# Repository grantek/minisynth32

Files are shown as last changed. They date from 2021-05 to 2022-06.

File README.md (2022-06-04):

# Minisynth 32

A 3D-printable MIDI synthesiser inspired by the Roland MT-32 and
[clumsyMIDI](https://github.com/gmcn42/clumsyMIDI), and powered by the
[mt32-pi](https://github.com/dwhinham/mt32-pi/wiki) MT-32 emulator.

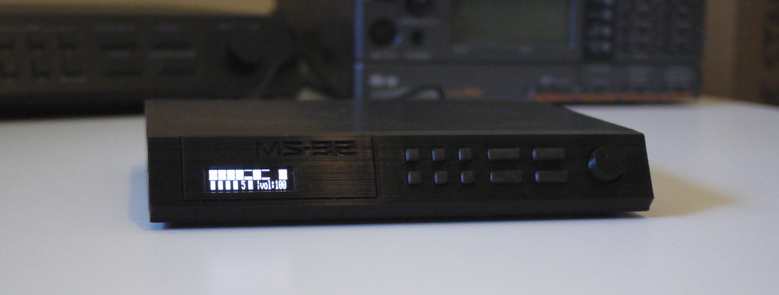
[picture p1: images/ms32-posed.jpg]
Minisynth 32


## Features

* 3D printable shell, 50% scale of the original MT-32
* GY-PCM5102 HiFi DAC board
* Front panel PCB with 2-10 tactile switches and 0.91" OLED Display
* Optional 2- or 10-button clickable front panel (only 2 buttons are functional)
* Rear I/O breakout PCB with 5.5mm power jack and pushbutton power switch
* Rotary encoder volume dial (generic 12mm shaft with no carrier board)
* MIDI Input via DIN5 MIDI cable or USB (using additional Arduino board)
* Completely through-hole soldering, no surface mount components
* Works with the Raspberry Pi "A" or "B" variants

## Warnings

**NO WARRANTY is provided, and no guarantee that all or any of the parts will
fit together. 3D printing is time-consuming and an art at the best of times.**

However, if you're stuck or have a question, feel free to open an issue on
GitHub, and the worst you'll get is sympathy.

## Assembly Notes

Check the [Bill of Materials](minisynth32-bom.csv) for all of the parts needed,
and the [project wiki](https://github.com/grantek/minisynth32/wiki) for the
build guide with pictures, a [text-only copy](build-guide.md) is included in
this repository.

## News

This is "Version 2.0" of the Minisynth 32, the previous version had a simpler
faceplate with 2 large, easy to print buttons. If you're looking for the old
version, see the "ms32-v1.0" tag/release.

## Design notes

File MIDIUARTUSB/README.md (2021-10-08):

# MIDI UART USB converter

This is a cut-down version of https://github.com/gdsports/MIDIUARTUSB for the
Minisynth 32. It only supports MIDI Out from the Tx line of the Arduino to the
Minisynth 32.

Install MIDI Library and MIDIUSB libraries using the Arduino IDE library manager.

Install support for the Sparkfun Pro Micro board in the Arduino IDE by
following the instructions at
https://learn.sparkfun.com/tutorials/pro-micro--fio-v3-hookup-guide/all

## Hardware

MIDIUARTUSB supports several boards based on the ATmega32U4, but the 3D models
for the Minisynth 32 have a spot for a Sparkfun Pro Micro board. I've tested
this with the 5v board only (clone boards are fine).

To interface with the MIDI In lines of the rear I/O PCB:

- Solder a 220 Ohm resistor to the TX0 pad and the VCC pad, each sticking
  straight up.
  - You don't need to leave any spacing between the resistors and the pads, but
    allowing enough to angle them helps with connecting the wires.
  - I haven't tested with a 3.3v Pro Micro board, but if you're using one of
    these, the MIDI specification suggests a 10 Ohm resistor on the TX0 pad,
    and a 33 Ohm resistor on the VCC pad.
- Solder a jumper wire (with a "DuPont" connector on the other end) to each of
  the resistors as per the instructions for connecting the DIN plug.
  - You can optionally add some heatshrink over the resistor-wire connection,
    but I found it wasn't needed.
- Connect the wire attached to the resistor on VCC to "Pin 4" on the rear I/O
  PCB, and the wire attached to the resistor on TX0 to "Pin 5".
- Fix the board to the base of the Minisynth 32 case with some double-sided
  tape.
- You can upload the sketch to the board before or after installing it into the
  Minisynth 32.

Once the sketch is uploaded, the board will show up as a "SparkFun Pro Micro"
when connected to USB, but this should show up as a standard MIDI device as
with any other type of cable.

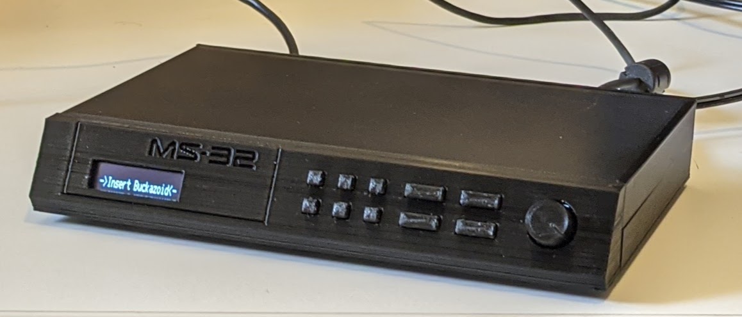
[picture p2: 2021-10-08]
images/ms32.jpg

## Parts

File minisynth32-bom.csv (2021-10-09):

PCBs
PCB Ref | Qnty | Value | Cmp name | Footprint | Description | Vendor
A1, | 1 | GY-PCM5102 | GY-PCM5102 | 1x06_P2.54mm (to attach) | GY-PCM5102 DAC board | Generic
C1, | 1 | 470u 10V | CP1 | Capacitor_THT:CP_Radial_D8.0mm_P3.50mm | Electrolytic capacitor
C2, C4, | 2 | 100n | C | Capacitor_THT:C_Rect_L7.0mm_W2.0mm_P5.00mm | Unpolarized bypass capacitor
C3, | 1 | 100u | CP1 | Capacitor_THT:C_Rect_L7.0mm_W2.0mm_P5.00mm | Electrolytic capacitor
D1, | 1 | 1N4148 | 1N4148 | Diode_THT:D_DO-35_SOD27_P7.62mm_Horizontal | 100V 0.15A standard switching diode, DO-35
J1, | 1 | F_PANEL | Conn_01x06 | 1x06_P2.54mm | Pin header, 6 pins, 90 degree angled
J2, | 1 | Conn_02x20_Odd_Even | Conn_02x20_Odd_Even | 2x20_P2.54mm | Generic connector, double row, 02x20
J3, | 1 | PJ-002A | PJ-002A | Custom THT | 5.5mm barrel power jack, 3-pin footprint | CUI Devices
J4, | 1 | ROT_HDR | Conn_01x04 | 1x04_P2.54mm | Pin header, 4 pins, 90 degree angled
J5, | 1 | MIDI_IN | Conn_01x02 | 1x02_P2.54mm | Pin header, 2 pins, 90 degree angled
J6, | 1 | R_BREAKOUT | Conn_01x06 | 1x06_P2.54mm | Pin header, 6 pins, vertical
J7, | 1 | SSD1306 OLED |  | 1x04_P2.54mm (to attach) | 0.91” OLED display with SSD1306 I2C board | Generic
R1, | 1 | 1k | R | Resistor_THT:R_Axial_DIN0207_L6.3mm_D2.5mm_P7.62mm_Horizontal | Resistor
R2, | 1 | 220R | R | Resistor_THT:R_Axial_DIN0207_L6.3mm_D2.5mm_P7.62mm_Horizontal | Resistor
SW1-SW10 | 10 | TL59NF160Q | TL59NF160Q | Custom THT | 6mm square * 4.3mm tall THT SPST momentary tactile switch | E-Switch
SW11 | 1 | PB400EEQR1BLK | PB400EEQR1BLK or PB400EEQX |  | DPST off-on pushbutton switch. PB400EEQR1BLK comes with a round black cap, PB400EEQX is the same thing without the cap (the round cap can be discarded) | E-Switch
 | 1 |  | TACBLK |  | Rectangular pushbutton cap – black | E-Switch
U1, | 1 | H11L1 | H11L1 | Package_DIP:DIP-6_W7.62mm | Schmitt Trigger Output Optocoupler, High Speed, DIP-6, 1.6mA turn on threshold
Totals:
J1,J4,J5 | 12 | Total angled pins required
J6,A1,J7 | 16 | Total vertical pins required
Other:
 | Qnty | Cmp name | Location | Notes
 | 12 | 2.54mm F-F jumper wires |  | AKA “DuPont” connectors, preferably joined in a ribbon, to be separated into 6-, 4-, and 2-wire ribbons
 | 4 | M2.5*8mm bolt | Raspberry Pi | 8-12mm length should work
 | 4 | M2.5 nut | Raspberry Pi
 | 4 | M3*8mm bolt | Faceplate and DIN socket/MCU clamp | 5-15mm length is fine, M2.5 bolts and nuts will also work here.
 | 4 | M3 nut | Faceplate and DIN socket/MCU clamp
 | 2 | M3*4mm screw | Faceplate and top shell
 | 2 | M3x3mm brass knurled threaded insert | Faceplate and top shell | Usually sold by 3D printing suppliers
 | 1 | 12mm rotary encoder with pushbutton |  | NOT pre-mounted onto a PCB. 12mm shaft height, 6mm shaft diameter
 | 4 | Adhesive rubber feet |  | eg. 3M Bumpon SJ-5508, but anything will work
 | 1 | Raspberry Pi 3 |  | Raspberry Pi 3A or 3B works with rev 1.1+ rear PCB
 | 1 | Micro SD card |  | Any capacity will fit mt32-pi
 | 1 | 5v AC adapter |  | 5.5*2.1mm barrel jack (to fit PJ-002A)
3D printed parts common for all variants:
 | Qnty | Filename | Description | Notes
 | 1 | knob-3.1mm.stl | Volume dial knob | See build guide for fitting notes
 | 1 | top.stl | Top shell
 | 1 | shim-2mm.stl | OLED shim | Helps align the OLED on the front PCB, see build guide for fitting notes
For 10-button face:
 | 1 | face.stl | 10-button face plate | See build guide for printing notes
 | 1 | buttonsheet.stl | 10-button flexible sheet | Print with 0.1mm layer height
For 2-button face:
 | 1 | face-2but.stl | 2-button face plate | Must be printed standing up (not face-down due to hard printed buttons)
 | 1 | buttonsheet-2but.stl | 2-button flexible sheet | Print with 0.1mm layer height
 | 2? | rectbutton.stl | Optional individual rectangular buttons | These have a wider base rather than a flexible sheet, and may be easier (or harder) to print.
 | -8 | TL59NF160Q | Tactile switch | Only 2 switches in total are needed in the B1 and B2 positions of the front PCB
For standard MIDI DIN base:
 | 1 | base-din.stl | Bottom shell | This uses the standard MIDI DIN connector
 | 1 | Panel-mount 180 degree 5-pin DIN connector |  | CUI Devices SD-50SN, but I’ve also seen these sold generically.
For USB base with microcontroller board:
 | 1 | base-mcu.stl | Bottom shell | See MIDIUARTUSB / build guide for notes and Arduino sketch
 | 1 | mcuclamp-sparkfun-pro-micro.stl | Clamp for SF Pro Micro board | See build guide if you need to adjust the height. mcuclamp-arduino-micro.stl suits the Ardiuino Micro.
 | 1 | Sparkfun Pro Micro board | 5v version preferred | Clone boards are usually okay as long as the microcontroller is genuine. Arduino Micro board will also work but extra length interferes with SD Card.
 | 2 | small strips of double-sided adhesive tape |  | To stick the MCU board to the base and add padding pressure. Thickness is around 2mm, otherwise adjust the clamp height.
 | 2 | 220R resistor | Axial lead | For 5v version of Sparkfun Pro Micro board
 | 1? | 10R resistor | Axial lead | Only if using a 3.3v MCU board (untested)
 | 1? | 33R resistor | Axial lead | Only if using a 3.3v MCU board (untested)

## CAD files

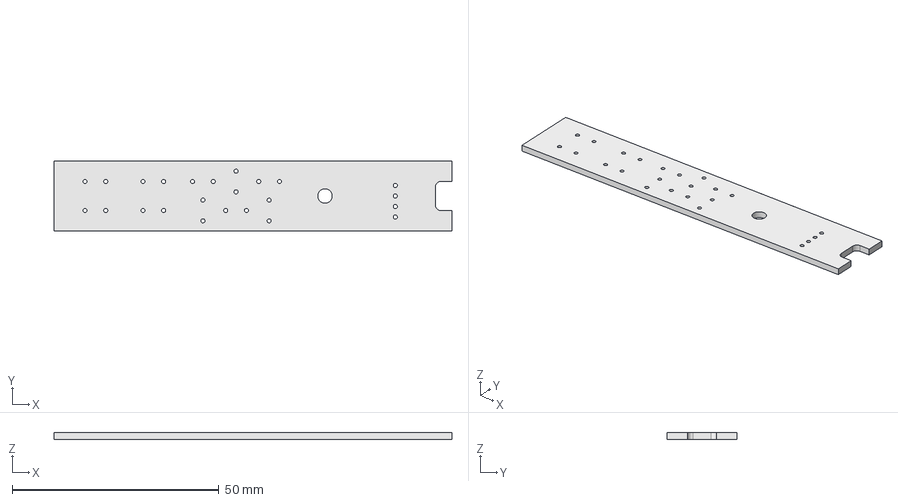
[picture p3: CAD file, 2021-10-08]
3d_models/pcbmock.FCStd
96.2 x 17.0 x 1.60 mm

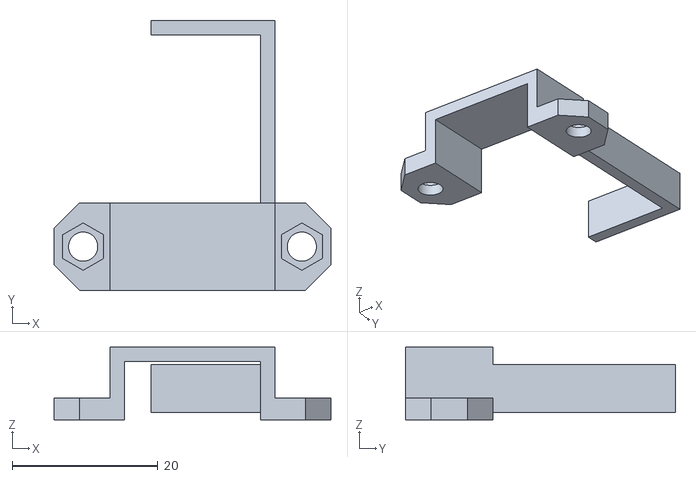
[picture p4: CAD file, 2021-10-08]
3d_models/mcuclamp-arduino-micro.stl
38.0 x 37.0 x 10.0

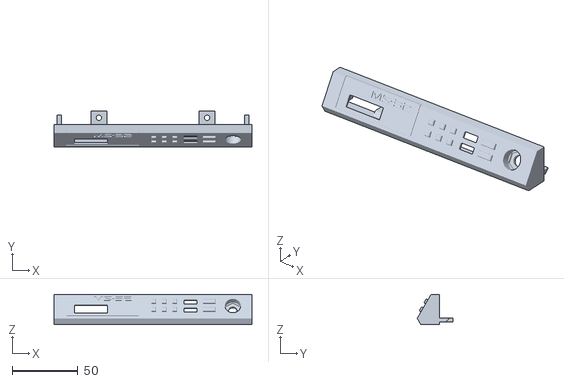
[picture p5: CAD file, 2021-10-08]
3d_models/face-2but.stl
150.0 x 27.0 x 22.9

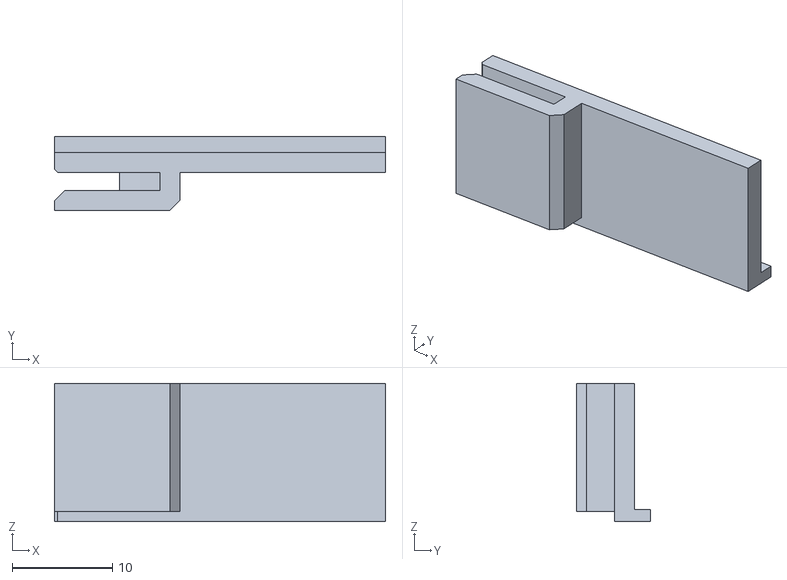
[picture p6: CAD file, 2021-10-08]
3d_models/shim-2mm.stl
33.0 x 7.40 x 13.8

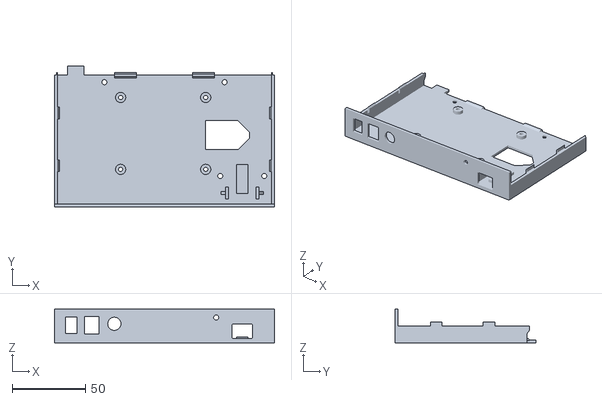
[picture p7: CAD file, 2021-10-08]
3d_models/base-mcu.stl
150.0 x 96.0 x 23.0

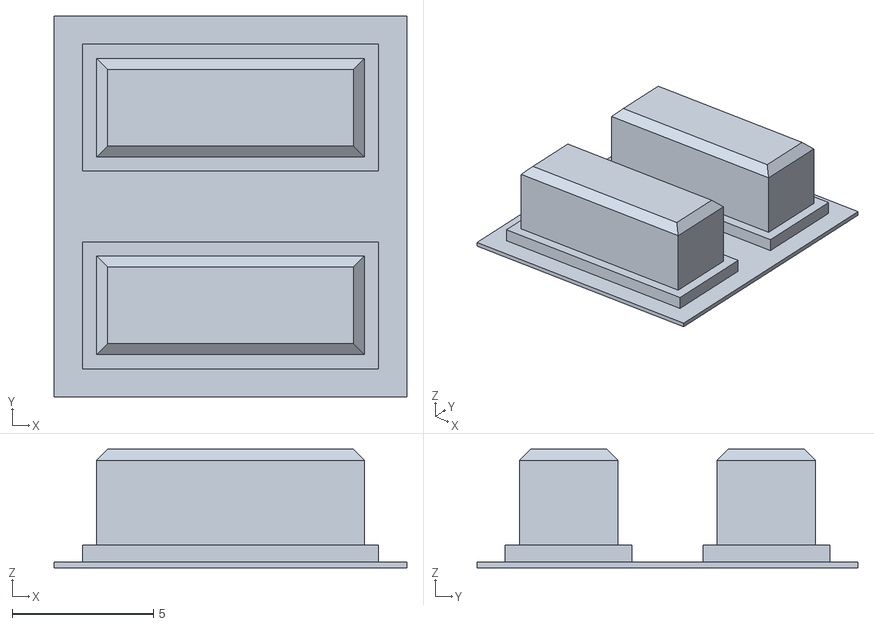
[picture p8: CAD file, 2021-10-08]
3d_models/buttonsheet-2button.stl
12.5 x 13.5 x 4.20

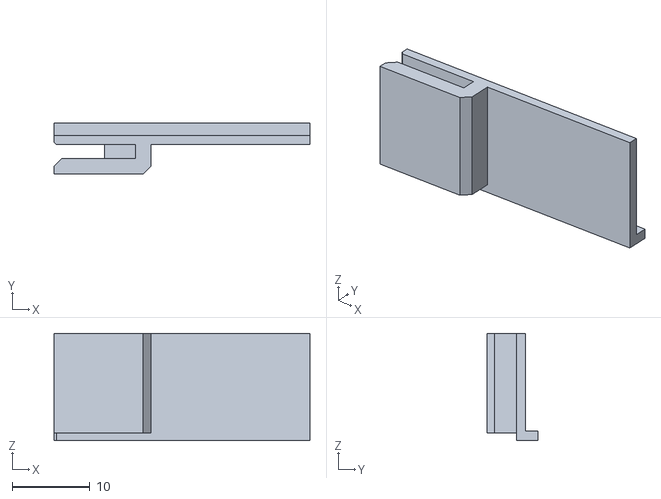
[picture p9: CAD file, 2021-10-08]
3d_models/shim-1.2mm.stl
33.0 x 6.60 x 13.8

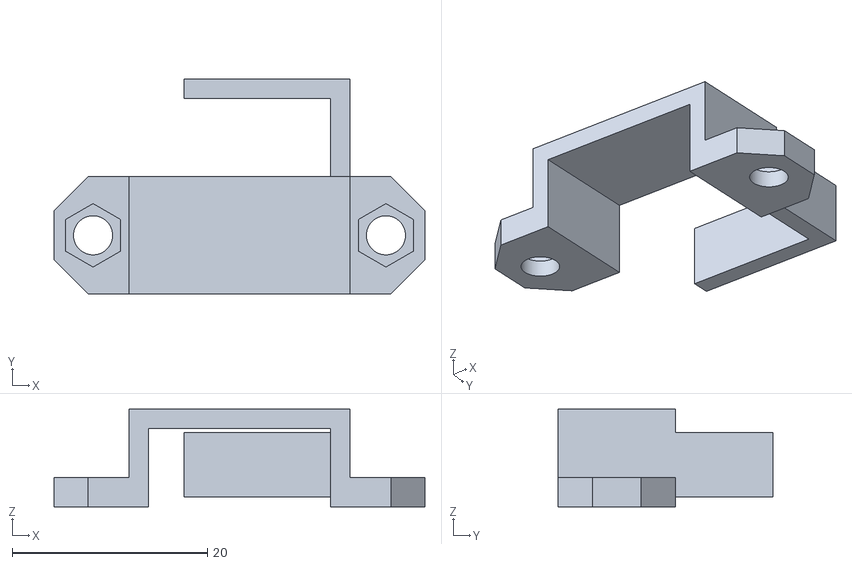
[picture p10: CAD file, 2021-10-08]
3d_models/mcuclamp-sparkfun-pro-micro.stl
38.0 x 22.0 x 10.0

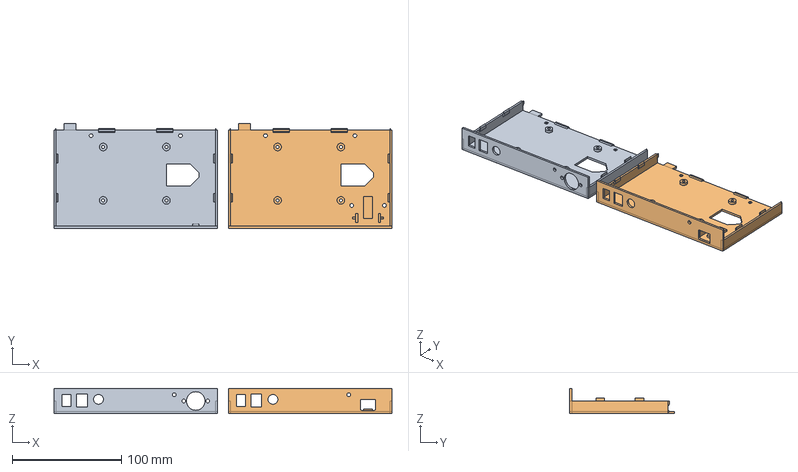
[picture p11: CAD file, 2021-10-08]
3d_models/base.FCStd
310.0 x 96.0 x 23.0 mm
base-din
base-mcu

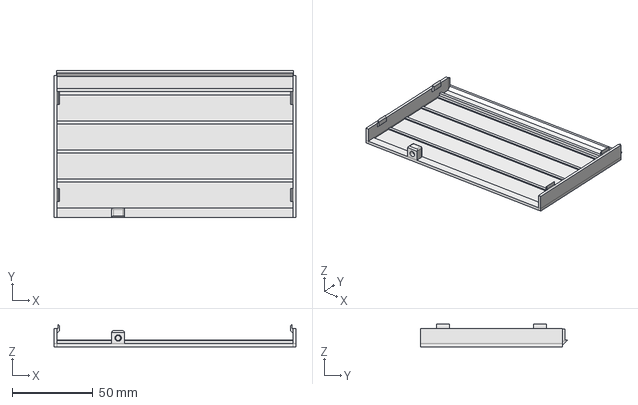
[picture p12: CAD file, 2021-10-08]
3d_models/top.FCStd
150.0 x 91.2 x 14.1 mm

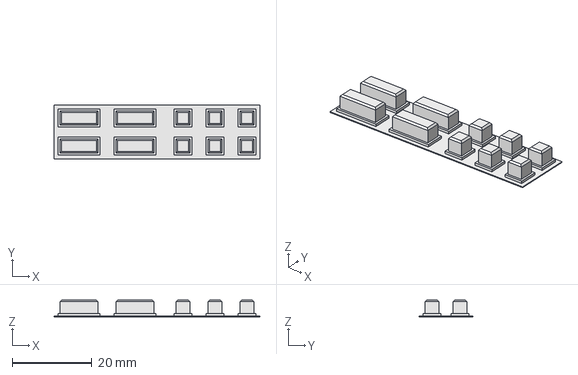
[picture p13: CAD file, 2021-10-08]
3d_models/buttonsheet.FCStd
51.5 x 13.5 x 4.20 mm

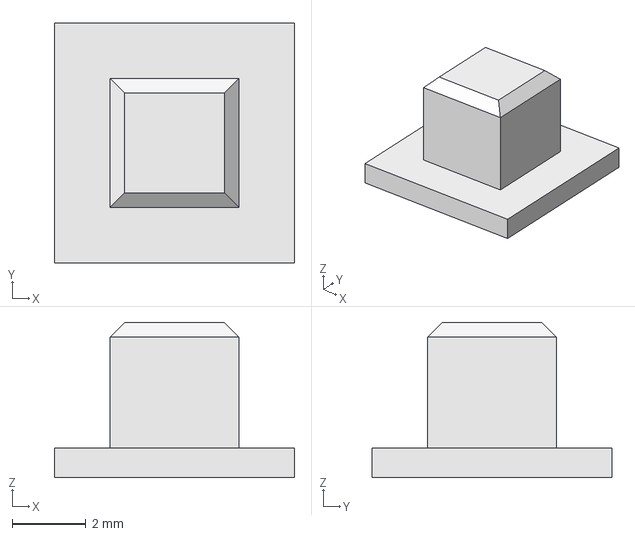
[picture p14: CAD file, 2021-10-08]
3d_models/squarebutton.FCStd
6.50 x 6.50 x 4.20 mm

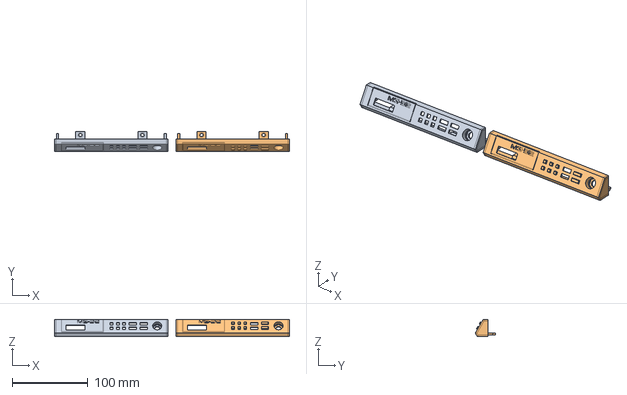
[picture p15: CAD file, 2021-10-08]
3d_models/face.FCStd
310.0 x 27.0 x 22.9 mm
face-2but

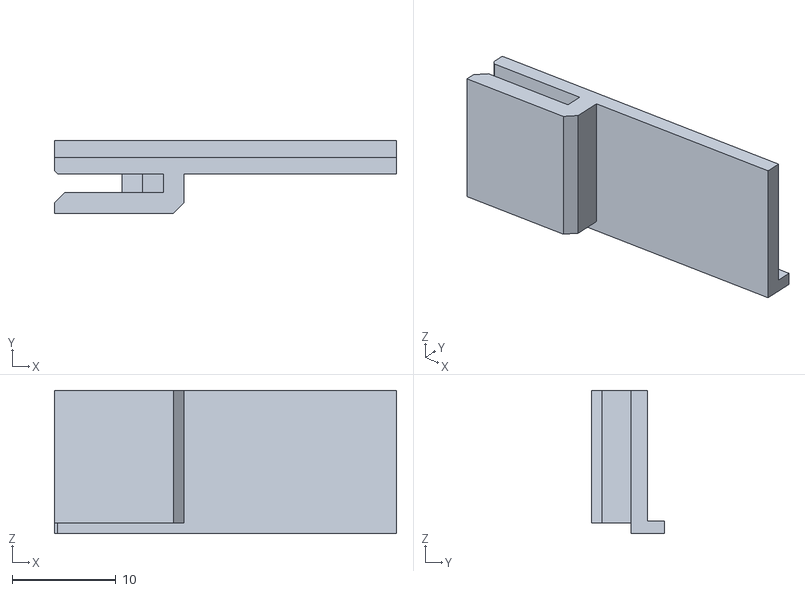
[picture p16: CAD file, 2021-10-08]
3d_models/shim-1.6mm.stl
33.0 x 7.00 x 13.8

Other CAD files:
3d_models/shim-0.8mm.stl
3d_models/rectbutton.FCStd
3d_models/shim.FCStd
3d_models/mcuclamp.FCStd
3d_models/base-din.stl
3d_models/buttonsheet.stl
3d_models/face.stl
3d_models/knob-3.0mm.FCStd
3d_models/knob-3.0mm.stl
3d_models/knob-3.1mm.FCStd
3d_models/knob-3.1mm.stl
3d_models/pcbmock.stl
3d_models/rebackplate.FCStd
3d_models/rectbutton.stl
3d_models/squarebutton.stl
3d_models/top.stl

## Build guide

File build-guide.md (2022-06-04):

# Minisynth 32 Build Guide

Check the [Bill of Materials](minisynth32-bom.csv) for all of the parts needed,
and the [project wiki](https://github.com/grantek/minisynth32/wiki) for the
build guide with pictures.

### MT32-pi configuration

A sample `mt32-pi.cfg` is included in this repository, the options that are
different from the default settings are:

```
# [midi]
# Disable USB input for faster boot time
usb = off

# [audio]
# Output audio to the GY-PCM5102 i2s board
output_device = i2s

# Initialise the GY-PCM5102 DAC on boot
i2c_dac_init = pcm51xx

# [control]
# Use the rotary encoder + 2 buttons control scheme
scheme = simple_encoder

# [lcd]
# Use the ssd1306 driver for the i2c OLED display
type = ssd1306_i2c

# invert the display since it's mounted upside-down in the Minisynth 32
rotation = inverted
```

* The generic 0.91" SSD1306 OLED also works with `height = 64`, and gives
  a sharper but smaller text display. The default `height = 32` is stretched
  but easier to read.
* The generic rotary encoder I used works fine with the `encoder_type = full`
  setting.
* Be sure to check the mt32-pi documentation for setting up the required MT-32
  ROMs and/or GM soundfonts, and other options you may be interested in.

### Choose your variant

#### DIN or USB MIDI input

The rear I/O panel is designed to accept a
[standard MIDI signal](https://www.midi.org/specifications-old/item/midi-din-electrical-specification)
for MIDI input, and the traditional connector for this (as on the Roland MT-32)
is a 180 degree DIN5 socket.

The "base-din.stl" base uses a panel-mount DIN5 socket (mounted on the inside)
connected directly to the input pins on the rear I/O board.

This is the most flexible setup, allowing you to plug in a MIDI cable from a
retro computer or keyboard, or any modern computer with a USB to MIDI cable.

The "base-mcu.stl" base allows you to mount a small Arduino-based
microcontroller board in place of the DIN socket. Using the MIDIUARTUSB sketch
(a cut-down version is included in this repo), the microcontroller acts as a
USB to MIDI cable, with the TX and 5v lines connected to the rear I/O board.

This allows you to connect the Minisynth 32 to a modern computer (or eg. to
a MiSTer) with nothing more than a USB cable

If you can't decide which version to make and don't have a USB to MIDI cable,
consider the DIN version, and make your own external USB to MIDI cable with
an Arduino, some resistors, and a DIN plug. Commercial cables can be found
cheaply, but the cheapest use chips that don't fully implement the MIDI
standard, and won't transmit the SYSEX messages required for MT-32
compatibility reliably.

#### Microcontroller board clamp

If using the USB base, the microcontroller board is clamped down against the
base with a plastic clip. The clip is intended to be used with foam mounting
tape to add some soft pressure to keep the board in place. If you're not using
tape or need to adjust the height of the clamp otherwise, open the
"mcuclamp.FCStd" model in FreeCAD, and adjust the "height of board + padding"
field.

The length of the clamp can also be adjusted to suit different boards.

#### 10-button or 2-button face

The hardware interface to mt32-pi currently only uses 2 buttons for interacting
with the software. The Minisynth 32 has a slightly more authentic 10-button
faceplate, with only 2 of the buttons functional and wired to the Raspberry Pi
(these are the rectangular buttons in the "Sound" and "Sound Group" positions
on the MT-32).

The 10-button version of the faceplate ("face.stl" and "buttonsheet.stl") uses
10 tactile switches to make each button "clickable", even though only 2 are
functional.

The 2-button version of the faceplate ("face-2but.stl" and
"buttonsheet-2button.stl") has clickable buttons in the "Sound" and "Sound
Group" positions, and 8 hard-printed buttons on the face model.

The 10-button version is recommended because it's easier to print (and tiny
clickable buttons are awesome), but the 2-button version is an option if for
some reason you prefer it.

#### Note about OLED board thickness

The 0.91" SSD1306 OLED boards aren't a branded standard, and depending on their
construction they may have different thicknesses. This is due to how the glass
screen is bonded to the PCB. Some use glue or thin tape to stick the glass to
the board, and some use a foam adhesive tape which is a bit thicker.

There is clearance between the Minisynth 32 front panel PCB and the inside of
the face plate to use a slightly thicker OLED board (you don't have to
disassemble and re-glue it), but to allow for different thicknesses (and to
keep the front PCB shorter than 100mm), there is a customiseable 3D-printed
shim that attaches to the front PCB and helps with soldering the OLED board.

The "shim-2mm.stl" is used for an OLED board with the glass directly bonded
to the PCB, and thinner shims can be used if you have an OLED board with some
space between the glass and the PCB.

See the front panel PCB section below for fitting notes. If you need to adjust
the thickness, open shim.FCStd in FreeCAD, open the spreadsheet named "vars",
and edit the value of "shim thickness", then export the shim model as an STL.

### The PCBs

There are 2 PCBs required, the Raspberry Pi hat that the rear connectors are
mounted onto (the "rear I/O breakout board"), and a mounting board for the
front panel. The "front" of the rear board faces downwards, so the components
hang upside down to fit in the tight clearance of the case. The MIDI port is
panel-mounted to the case for the same reason.

The KiCad project is based on a combined board with both PCBs joined by mouse-
bites, so they can be ordered as a single panel. There are also files for the
individual front and rear boards, because it was cheaper for me to order them
this way from the PCB manufacturer I used (there was an extra fee for
"panelised" boards that was more than double the base cost of a single small
board).

PCB notes for manufacturers:

* Rear PCB only (v1.1): 31.7mm * 96mm
* Front PCB only (v2.0): 17mm * 96.2mm
* Panelised front+rear PCB: 51.3mm * 96.2mm
* Minimum hole size: 0.5mm (the standard "0.3mm" is fine to select)
* Minimum track spacing: 0.2mm (the standard "6 mils" is fine to select)
* Layers: 2
* Thickness: must be 1.6mm

### 3D Printing the shell

I'm using a standard hobbyist FFF printer with black PLA filament. The
face plate is kind of terrible for this kind of printing process due to the
different angles involved, but I was successful in printing it upright at a
0.2mm layer height, with the visible layer lines horizontal in the finished
part.

Specifically, use "tree" support for the face if your slicer has the option,
which builds a tower of support starting on the build plate where possible and
reaching across to the overhanging parts.

Regardless of the type of support, there will still be some on the inside of
the faceplate, You need to be thorough in removing it from the inside floor of
the faceplate because the front panel needs to fit in there, but there is some
clearance so one or two layers of support stuck to the floor is okay. Careful
use of a scalpel can help reach behind the PCB support behind the buttons.

The other parts are more straightforward to print, but read through the other
sections for notes on customisation.

The shell was modeled in FreeCAD using the Part workbench, which uses simple
geometric shapes added and subtracted from each other. If you want to modify
the "MS-32" text on the face plate to something more authentic, select the
Model window, press Ctrl-F to search the tree of objects, and search for
ShapeString (the default name for a text object). In the Data window for the
selected object you should be able to change the "MS-32" to something else, and
press Enter. You may also need to supply the font file, I used the "TR-909"
font freely available online.

If the faceplate doesn't update immediately, you should see a check mark on
one or more objects in the tree. Right click on the top-level "face" object
and select "Recompute object".

### Assembling the front panel PCB

See the [Choose your variant](#choose-your-variant) section for options here,
you should have 10 or 2 tactile switches, and a 3D-printed shim to suit your
OLED board.

If you're installing 10 tactile switches, solder these first, as it's easy to
fit them all and then flip the board over with the PCB laying flat on them
before soldering. It doesn't matter if the switches aren't perfectly aligned
in rotation, as long as they're all flat against the PCB.

Take a 4-pin vertical header and solder it to the back of the OLED board, so
that the plastic collar and long ends of the pins face backwards. Solder the
short ends of the pins to the solder points on the front of the board, using
the plastic collar on the back to keep them perpendicular.

If you're using a shim thinner than 1.6mm, you'll need to slide the plastic
collar off the pins so that the OLED board can sit close to the front panel
board (use a blade to start levering the collar backwards).

Clip the shim to the front panel board so that the flat section is on the front
and the tab inside the shim's clip fits into the notch on the front panel
board.

Ideally, do a test fit with the OLED board and shim by installing the board
on top of the shim without soldering the pins onto the front panel PCB, and
try fitting it into the front faceplate. If the PCB doesn't sit flush against
the mounting hole on the faceplate without bending, the shim is too thick.

Once you have a good fit, solder the pins in the front panel board and trim
them.

Solder a 6-pin vertical header to the back of the front panel PCB in the
`R_BREAKOUT` position. The `UNUSED` headers are connected to the non-functional
buttons and don't need pins unless you're experimenting.

### Assembling the rear I/O PCB

The main soldering advice is to solder the DAC board first (see below), then
the generic "lowest-height components first". Make sure to trim all legs on the
underside of the rear breakout PCB, as this faces upwards and there isn't
much room to the printed case.

####  Soldering the DAC module

**IMPORTANT:** As per the clumsyMIDI documentation, make sure that all 4 solder
pad "jumpers" on the GY-PCM5102 board are set BEFORE soldering it to the board.
To solder the GY-PCM5102 DAC board:

- Check the soldered pad headers on the rear of the GY-PCM5102 a final time.
- Solder a 6-pin header to the back of the board (on the short edge), and slide
  the plastic collar off, like the OLED board when using a thin shim.
- Solder the pins through the rear PCB. Alignment of the DAC board is less
  critical here, I used a 2-layer paper shim to help position it while
  soldering it.
- You don't need to solder anything to the row of 9 pins on the long edge,
  there is no connection to anything on the rear breakout board.

####  Soldering the rear panel pin headers

There are 3 pin headers on the rear breakout board that require a 90-degree
angled pin header:

- `F_PANEL`: connects to the front panel PCB, 6 pins.
- `ROT_HDR`: connects to the rotary encoder, 4 pins.
- `MIDI_IN:`: connects to the panel-mount DIN5 jack for MIDI input.

Check the clearance of your pin headers against the Raspberry Pi - if you have
tall pin headers, push them down through the plastic collar so that they just
have room for the jumper wires to connect.

### Assembling the rotary encoder

The rotary encoder used is a "12mm" generic device available online.
Specifically, this is **NOT** a preassembled board with 5-pin header, there's
not enough room for these, so you need to wire directly to the bare legs.

First, bend the mounting tabs on the encoder in against its base.

The pinout from the rear I/O board is labelled `GND` `SW` `B` `A`

* Take a 4-wire jumper cable (ie. with "DuPont" 2.54mm pitch female
  connectors), cut the connectors off one end, strip and tin the cut end of the
  wires.
* When soldering the cut ends to the rotary encoder, you can optionally use
  heatshrink to prevent the exposed legs from touching each other.
* Solder the `GND` wire to the middle pin of the 3-pin side, and from there
  (using another short piece of wire) connect it to one of the
  pins on the 2-pin side.
* Solder the `SW` wire to the other pin on the 2-pin side.
* Solder the `B` wire to the pin on the left of the GND pin.
* Solder the `A` wire to the pin on the right of the GND pin.
* If you get the `B` and `A` pins wrong, you can swap the jumper wires on the
  pin header of the rear breakout board.

The 3D-printed knob for the rotary encoder can be hard to attach firmly. I
found printing the knob in PET-G was best to get a firm fit, but PLA was
less flexible, If the knob won't attach, you can carefully use a clean hot
soldering iron pressed against the rotary encoder's shaft to soften the plastic
in a similar way to the knurled screw inserts. If it's too loose, use some putty
adhesive to hold it in place (this is much easier). There are a few STLs of
different shaft widths, but the FreeCAD model is also easy to modify.

Make sure you have a good fit for the knob before assembling the face plate,
but leave it off when inserting the rotary encoder.

### Assembling the MIDI port for the DIN base

This is similar to the rotary encoder, but it just requires 2 jumper wires
soldered onto the panel-mount DIN5 jack. Looking at the face of the jack with
the pins facing upwards, pin 4 is immediately to the left of the middle pin and
pin 5 is on the right. Heatshrink isn't needed for insulation because the pins
are so far apart, but I used heatshrink to add some mechanical stability to the
connection.

### Setting up the MCU board for the USB base

This repository has 3D models to suit the Sparkfun Pro Micro board (an Arduino-
compatible board), and the Arduino Micro board. The Sparkfun Pro Micro is
recommended because it's shorter and doesn't interfere with the SD card port,
but any of the Arduino boards that use the ATmega32U4 microcontroller will be
compatible if you can fit it in (as mentioned in the intro, you can also leave
the Arduino outside the box as a separate USB-MIDI adapter).

Configuring the Arduino IDE to upload the sketch is outside the scope of this
project, see the links in the [MIDIUARTUSB README](MIDIUARTUSB/README.md).
Things to note:

- Install the MIDI and MIDIUSB libraries in the Arduino IDE
- Install support for the Sparkfun board using the instructions at sparkfun.com

Once you've uploaded the sketch to the board, you need to add resistors and
wires to the board. Solder a 220 ohm resistor onto each of the TX and VCC
points (TX and 5v for the Arduino Micro), and solder DuPont wires in the
way as the DIN port/rotary encoder.

If using a 3.3v microcontroller board, use a 33 ohm resistor on the VCC line and
a 10 ohm resistor on the TX line.

### Assembling the shell

The Raspberry Pi is mounted using M2.5 bolts and nuts. M3 bolts _may_ work
(older versions of the base used M3 screws into threaded inserts), but require
widening the hole slightly, which carries some risk of damaging the Pi.

The faceplate and MIDI port are attached using M3 bolts and nuts. The bolt
lengths don't matter too much, 8-15mm is good. 8mm M2.5 bolts and nuts will also
work here if you're purchasing one type of bolt.

The front PCB, rotary encoder, and top shell are attached using M3\*4mm screws.
M3 PC Case Screws may work here, but if they're any longer than 4mm, it's
possible to push into the plastic resulting in a bulge on the front.

The mounting holes for the front panel PCB, and the top shell use 3mm M3
knurled threaded inserts. These are pushed into the (slightly narrower)
mounting holes of the plastic case with a hot soldering iron to melt them into
the hole (use a similar temperature as your 3D printer extruder, eg. 220-250
Celsius for PLA).

  *  Be careful you don't let the soldering iron touch the other 3D-printed
     parts!
  *  It's easy with a wide conical soldering tip to push the tip of the iron
     into the insert, and hold the insert down with tweezers while you remove
     the iron tip.

### Assembling the face

* Melt the first threaded insert into the faceplate as described above.
* Melt the other threaded insert into the mounting hole on the top shell while
  you're at it.
* The printed face plate is assembled with the assembled front panel PCB, the
  printed button sheet, and the printed knob on the rotary encoder.
* Drop the printed button sheet into the button holes, then fit the front panel
  PCB so that the tactile switches fit against the buttons, and the OLED display
  is aligned with the window. Attach the PCB with an M3 screw.
* Install the rotary encoder:

Remove the hexagonal nut and washer from the encoder, and simply screw the
encoder shaft into the faceplate. There's a cutout in the faceplate to allow
the encoder to spin, but pliers are helpful to rotate it carefully. You may
need to keep screwing it into the plastic once it's in, and slightly strip away
some plastic to get it to line up straight (you'll notice this when installing
the knob).

If the encoder doesn't screw in tightly to the plastic face, put the hexagonal
nut from the rotary encoder into the hexagonal relief in the front of the
faceplate, then screw in the encoder. Even if you prefer to use the hexagonal
nut regardless, screw the encoder into the plastic first to get it straight.

### Assembling the base and top

* Format and prepare your Micro SD card for mt32-pi, and insert it into the
  Raspberry Pi. You can still access the SD card when the Pi is installed, but
  it's easier to do it beforehand.
* Attach the assembled Rear I/O PCB onto the Pi's 40-pin GPIO port, facing
  outwards.
* Line up the Pi on the base with the rear panel, and insert 4 M2.5 bolts
  through the base and mounting holes on the Pi. Secure with 4 M2.5 nuts, but
  do not over-tighten these as excess pressure can damage the Pi.

#### Install the DIN port in the MIDI DIN base

* Place the wired MIDI DIN jack on the **inside** of the base's rear plate, and
  attach with 2 M3 bolts from the outside (M3 nuts on the inside). The DIN5
  jack is traditionally mounted with the pins facing down, and the alignment
  notch facing up. DIN5 cables have an an arrow at the alignment notch for easy
  attachment.
* Connect the DIN jack to the labelled pins on the rear PCB `MIDI_IN` header.
  With the half-circle of DIN pins facing downwards, Pin 4 is left of the
  centre solder tab, and when connected to the rear PCB, the jumper wires
  won't cross.

#### Install the MCU board in the USB base

* Use a piece of padded foam adhesive tape to stick the microcontroller board
  onto the raised section of the base.
* Put a piece of padded foam adhesive tape on top of the ATMega32U4 chip to
  press against the clamp.
* Put the clamp over the MCU board and align the bolt holes.
* Use 3mm bolts and hex nuts to bolt the clamp down and secure the board.
* Connect the VCC/5v wire to Pin 4 on the rear I/O board, and TX to Pin 5.

#### Finishing up

* Connect the wired rotary encoder to the `ROT_HDR` header.
* Use a row of 6 female-female jumper wires to connect the front panel's
  `R_BREAKOUT` header to the rear breakout board's `F_PANEL` header.
* Insert the face plate's tabs into the base, insert a bolt from the bottom of
  the base through each tab in the face plate and fasten with an M3 nut.
* Fit the top shell and fasten with an M3 screw.
* Stick 4 rubber feet (or felt pads, etc.) to the base to give clearance for the
  bolt heads.

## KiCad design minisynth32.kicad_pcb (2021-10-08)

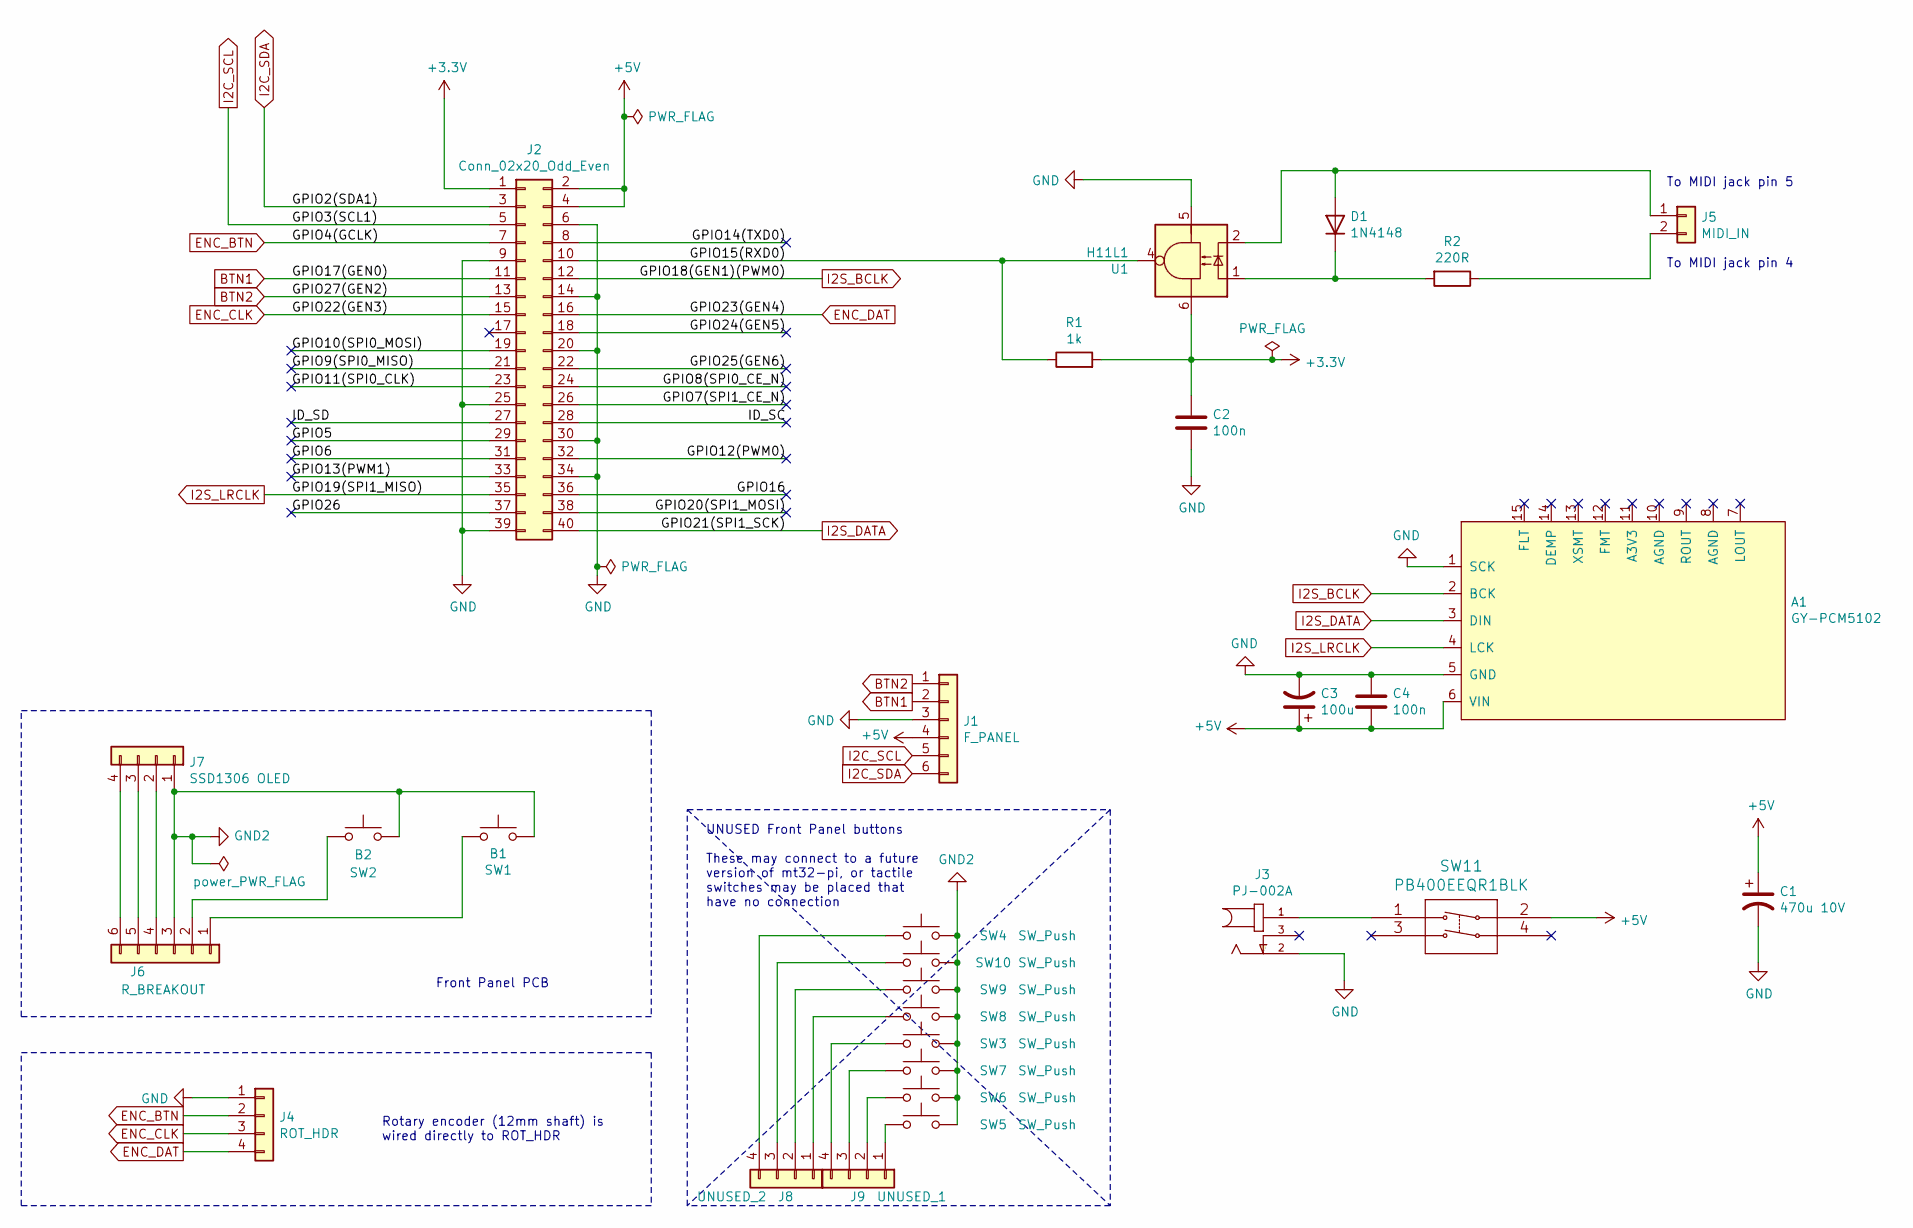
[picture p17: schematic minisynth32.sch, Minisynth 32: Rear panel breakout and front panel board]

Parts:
A1: GY-PCM5102
C1: 470u 10V; CP_Radial_D8.0mm_P3.50mm
C2, C4: 100n; C_Rect_L7.0mm_W2.0mm_P5.00mm
C3: 100u; CP_Radial_D6.3mm_P2.50mm
D1: 1N4148; D_DO-35_SOD27_P7.62mm_Horizontal
J1: F_PANEL; PinHeader_1x06_P2.54mm_Vertical
J2: Conn_02x20_Odd_Even; PinSocket_2x20_P2.54mm_Vertical
J3: PJ-002A; CUI_PJ-002A
J4: ROT_HDR; PinHeader_1x04_P2.54mm_Vertical
J5: MIDI_IN; PinHeader_1x02_P2.54mm_Vertical
J6: R_BREAKOUT; PinHeader_1x06_P2.54mm_Vertical
J7: SSD1306 OLED; SSD1306_128_32
J8: UNUSED_2; PinHeader_1x04_P2.54mm_Vertical
J9: UNUSED_1; PinHeader_1x04_P2.54mm_Vertical
R1: 1k; R_Axial_DIN0207_L6.3mm_D2.5mm_P10.16mm_Horizontal
R2: 220R; R_Axial_DIN0207_L6.3mm_D2.5mm_P10.16mm_Horizontal
SW1: B1; TL59N
SW2: B2; TL59N
SW3, SW4, SW5, SW6, SW7, SW8, SW9, SW10: SW_Push; TL59N
SW11: PB400EEQR1BLK
U1: H11L1; DIP-6_W7.62mm

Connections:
+3V3: C2.1, J2.1, R1.2, U1.6
+5V: A1.6 (VIN), C1.1, C3.1, C4.1, J1.4, J2.2, J2.4, SW11.2
/GPIO5: J2.29
/GPIO6: J2.31
/GPIO7(SPI1_CE_N): J2.26
/GPIO8(SPI0_CE_N): J2.24
/GPIO9(SPI0_MISO): J2.21
/GPIO10(SPI0_MOSI): J2.19
/GPIO11(SPI0_CLK): J2.23
/GPIO12(PWM0): J2.32
/GPIO13(PWM1): J2.33
/GPIO14(TXD0): J2.8
/GPIO15(RXD0): J2.10, R1.1, U1.4
/GPIO16: J2.36
/GPIO20(SPI1_MOSI): J2.38
/GPIO24(GEN5): J2.18
/GPIO25(GEN6): J2.22
/GPIO26: J2.37
/ID_SC: J2.28
/ID_SD: J2.27
BTN1: J1.2, J2.11
BTN2: J1.1, J2.13
ENC_BTN: J2.7, J4.2
ENC_CLK: J2.15, J4.3
ENC_DAT: J2.16, J4.4
GND: A1.1 (SCK), A1.5 (GND), C1.2, C2.2, C3.2, C4.2, J1.3, J2.6, J2.9, J2.14, J2.20, J2.25, J2.30, J2.34, J2.39, J3.2, J4.1, U1.5
GND2: J6.3, J7.1, SW1.2, SW2.2, SW3.2, SW4.2, SW5.2, SW6.2, SW7.2, SW8.2, SW9.2, SW10.2
I2C_SCL: J1.5, J2.5
I2C_SDA: J1.6, J2.3
I2S_BCLK: A1.2 (BCK), J2.12
I2S_DATA: A1.3 (DIN), J2.40
I2S_LRCLK: A1.4 (LCK), J2.35
unnamed: D1.1 (K), R2.2, U1.1
unnamed: D1.2 (A), J5.1, U1.2
unnamed: J3.1, SW11.1
unnamed: J5.2, R2.1
unnamed: J6.1, SW1.1
unnamed: J6.2, SW2.1
unnamed: J6.4, J7.2
unnamed: J6.5, J7.3
unnamed: J6.6, J7.4
unnamed: J8.1, SW8.1
unnamed: J8.2, SW9.1
unnamed: J8.3, SW10.1
unnamed: J8.4, SW4.1
unnamed: J9.1, SW5.1
unnamed: J9.2, SW6.1
unnamed: J9.3, SW7.1
unnamed: J9.4, SW3.1

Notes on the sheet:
To MIDI jack pin 4
To MIDI jack pin 5
Rotary encoder (12mm shaft) is wired directly to ROT_HDR
Front Panel PCB
UNUSED Front Panel buttons These may connect to a future version of mt32-pi, or tactile switches may be placed that have no connection

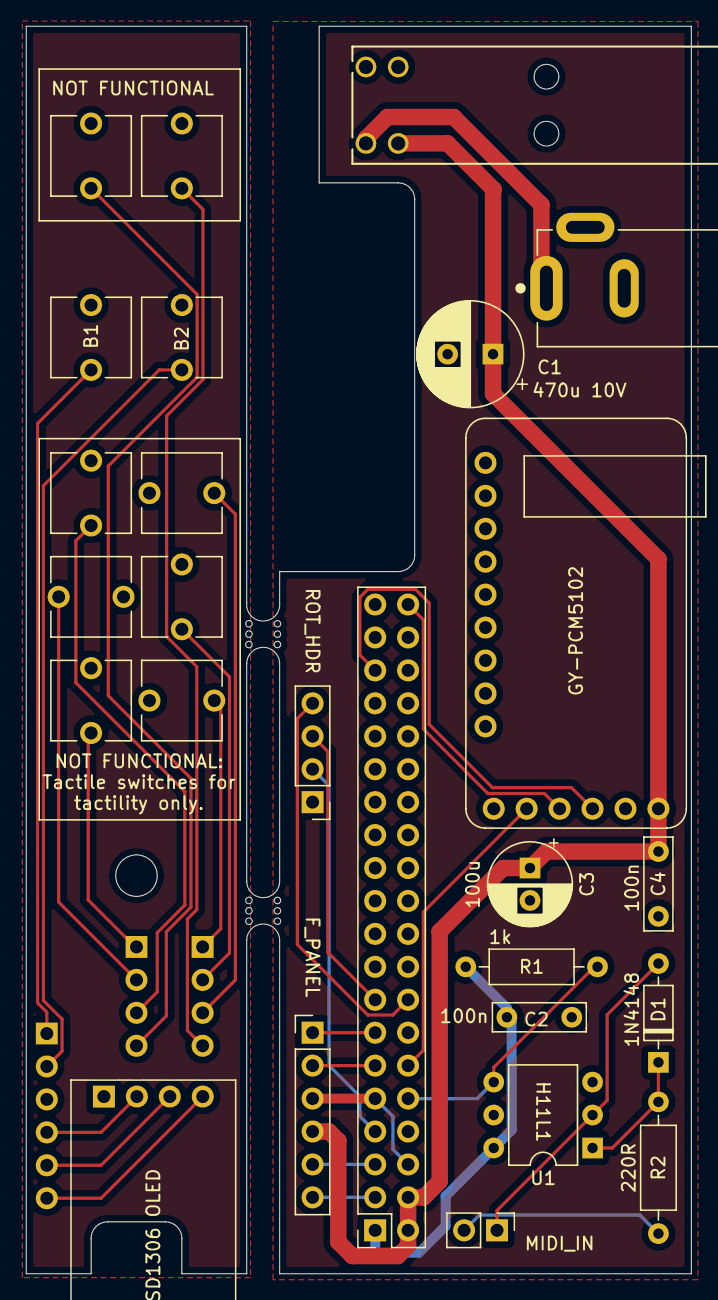
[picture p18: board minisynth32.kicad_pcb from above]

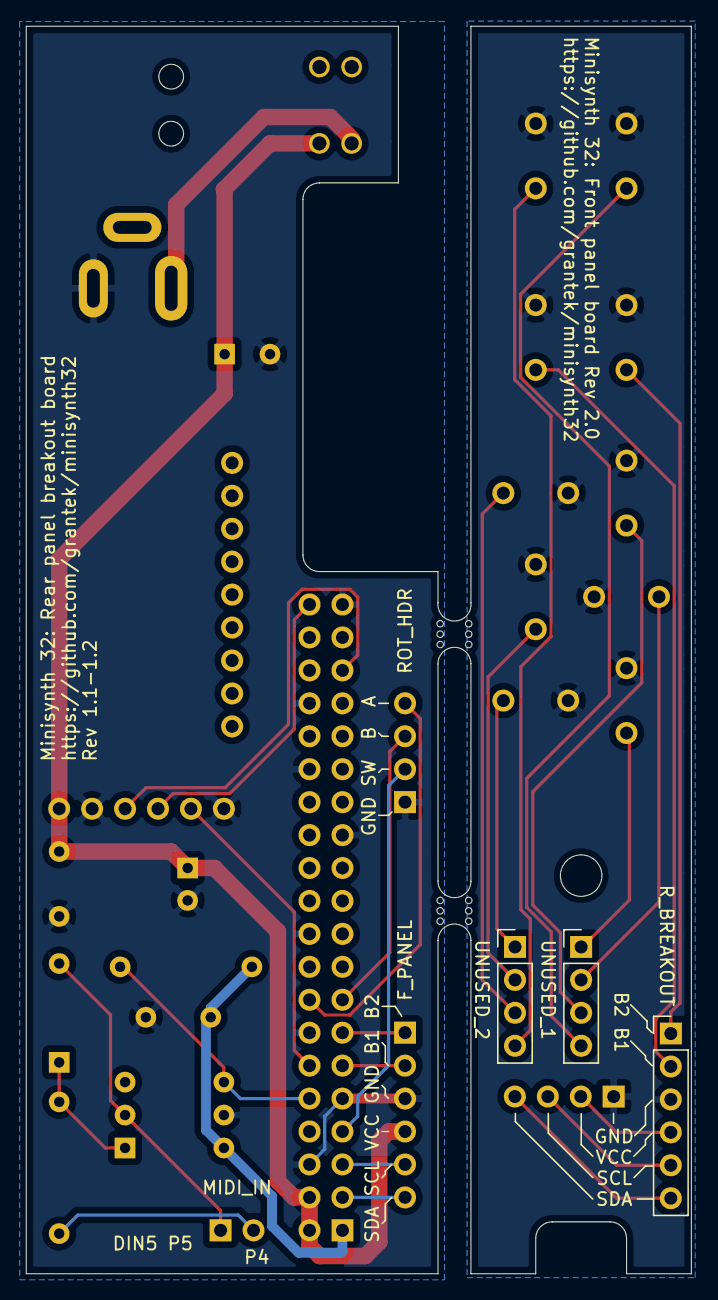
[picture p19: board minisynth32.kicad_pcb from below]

Board: 2 copper layers, 51.3 x 96.2 mm, 31 parts (3 on the bottom side), 32 nets.

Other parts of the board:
mouse-bite-2.54mm-slot, mouse-bite-2.54mm-slot#2: VAL**; mouse-bite-2.54mm-slot

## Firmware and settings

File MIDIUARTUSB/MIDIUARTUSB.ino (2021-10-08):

/*
  MIT License

  Copyright (c) 2018 gdsports625@gmail.com

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
  THE SOFTWARE IS PROVIDED "AS IS", WITHOUT WARRANTY OF ANY KIND, EXPRESS OR
  IMPLIED, INCLUDING BUT NOT LIMITED TO THE WARRANTIES OF MERCHANTABILITY,
  FITNESS FOR A PARTICULAR PURPOSE AND NONINFRINGEMENT. IN NO EVENT SHALL THE
  AUTHORS OR COPYRIGHT HOLDERS BE LIABLE FOR ANY CLAIM, DAMAGES OR OTHER
  LIABILITY, WHETHER IN AN ACTION OF CONTRACT, TORT OR OTHERWISE, ARISING FROM,
  OUT OF OR IN CONNECTION WITH THE SOFTWARE OR THE USE OR OTHER DEALINGS IN THE
  SOFTWARE.
*/

/*
   MIDIUARTUSB converter for 32u4 such as Leonardo, Pro Micro, Itsy Bitsy.

   Original sketch: https://github.com/gdsports/MIDIUARTUSB

   Modified for Minisynth32 to only include "MIDI out" functionality to the
   synth unit.

   Intended for Ardiono Pro Micro, but see the main project for notes on other
   boards this may work with.
*/

#include <MIDI.h>
#include <MIDIUSB.h>

// 1 turns on debug, 0 off
#define DBGSERIAL if (0) SERIAL_PORT_MONITOR
#ifdef USBCON
#define MIDI_SERIAL_PORT Serial1
#else
#define MIDI_SERIAL_PORT Serial
#endif

struct MySettings : public midi::DefaultSettings
{
  static const bool Use1ByteParsing = false;
  static const unsigned SysExMaxSize = 1026; // Accept SysEx messages up to 1024 bytes long.
  static const long BaudRate = 31250;
};

MIDI_CREATE_CUSTOM_INSTANCE(HardwareSerial, MIDI_SERIAL_PORT, MIDIUART, MySettings);

inline uint8_t writeUARTwait(uint8_t *p, uint16_t size)
{
  // Apparently, not needed. write blocks, if needed
  //  while (MIDI_SERIAL_PORT.availableForWrite() < size) {
  //    delay(1);
  //  }
  return MIDI_SERIAL_PORT.write(p, size);
}

uint16_t sysexSize = 0;

void sysex_end(uint8_t i)
{
  sysexSize += i;
  sysexSize = 0;
}

const uint8_t MIDI_passthru_pin=2;
bool MIDI_passthru;

void setup() {
  // Turn off built-in RED LED
  pinMode(LED_BUILTIN, OUTPUT);
  digitalWrite(LED_BUILTIN, LOW);

  DBGSERIAL.begin(115200);

  // Pin 0 LOW selects MIDI pass through on
  pinMode(MIDI_passthru_pin, INPUT_PULLUP);
  MIDI_passthru = (digitalRead(MIDI_passthru_pin) == LOW);

  MIDIUART.begin(MIDI_CHANNEL_OMNI);
  if (MIDI_passthru) {
    DBGSERIAL.println("MIDI thru on");
  }
  else {
    DBGSERIAL.println("MIDI thru off");
    MIDIUART.turnThruOff();
  }
}

void loop()
{
  /* MIDI USB -> MIDI UART */
  midiEventPacket_t rx = MidiUSB.read();
  if (rx.header != 0) {
    switch (rx.header & 0x0F) {
      case 0x00:  // Misc. Reserved for future extensions.
        break;
      case 0x01:  // Cable events. Reserved for future expansion.
        break;
      case 0x02:  // Two-byte System Common messages
      case 0x0C:  // Program Change
      case 0x0D:  // Channel Pressure
        writeUARTwait(&rx.byte1, 2);
        break;
      case 0x03:  // Three-byte System Common messages
      case 0x08:  // Note-off
      case 0x09:  // Note-on
      case 0x0A:  // Poly-KeyPress
      case 0x0B:  // Control Change
      case 0x0E:  // PitchBend Change
        writeUARTwait(&rx.byte1, 3);
        break;
      case 0x04:  // SysEx starts or continues
        sysexSize += 3;
        writeUARTwait(&rx.byte1, 3);
        break;
      case 0x05:  // Single-byte System Common Message or SysEx ends with the following single byte
        sysex_end(1);
        writeUARTwait(&rx.byte1, 1);
        break;
      case 0x06:  // SysEx ends with the following two bytes
        sysex_end(2);
        writeUARTwait(&rx.byte1, 2);
        break;
      case 0x07:  // SysEx ends with the following three bytes
        sysex_end(3);
        writeUARTwait(&rx.byte1, 3);
        break;
      case 0x0F:  // Single Byte, TuneRequest, Clock, Start, Continue, Stop, etc.
        writeUARTwait(&rx.byte1, 1);
        break;
    }
  }
}

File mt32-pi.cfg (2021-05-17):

#                                  ________    _______                      __
#                         __      /_____   `. /____   `.                   /__`
#     ____   ____     __/  /____  _______)  / ______)  / ____  ______      __
#   /   __ v  __  `./__   _____//_____    < /   _____. /____//   ___  `. /  /
#  /  /  /  /  /  /   /  /____  _______)  //  /______       /  /____/  //  .__
# /__/  /__/  /__/    \______//_________. /_________/      /   ______.  \____/
# /////////////////////////////////////////////////////// /  / //// /// // /
#                                                         ```
# mt32-pi.cfg: mt32-pi configuration file.
# Default options are marked with an asterisk (*).

# -----------------------------------------------------------------------------
# System options
# -----------------------------------------------------------------------------
[system]

# Set the default synthesizer to be made active on startup.
#
# If the default synthesizer is unavailable (e.g. missing ROMs or SoundFonts),
# the first working synth is made active.
#
# Values: mt32*, soundfont
#
# mt32:      Use mt32emu (Munt) for Roland MT-32 emulation
# soundfont: Use FluidSynth for SoundFont synthesis
default_synth = mt32

# Enable or disable support for USB devices.
#
# Disable this to speed up boot time if you are not using any USB devices.
#
# Values: on*, off
usb = off

# Set the I2C baud rate/clock speed for all peripherals (Hz).
#
# Most peripherals will work fine at the default speed (400KHz "fast mode"),
# but larger LCD/OLED displays (e.g. 4-line I2C HD44780 and 64 pixel high
# SSD1306) won't be able to refresh at 60FPS at the default setting.
#
# Try increasing this value to 1000000 (1MHz) for a smoother LCD refresh rate.
# If your display doesn't work, try backing off the speed 100KHz at a time
# until it does.
#
# Values: 100000-1000000 (400000*)
i2c_baud_rate = 400000

# Set the timeout for power saving mode (seconds).
#
# After the specified number of seconds of silence, the CPU clock speed will be
# reduced, the audio device will be stopped, and and the LCD's backlight will
# be turned off to save energy (certain I2C displays only).
#
# Any MIDI activity will instantly bring the system out of power saving mode.
#
# If set to 0, power saving mode is disabled.
#
# Values: 0-3600 (300*)
power_save_timeout = 300

# -----------------------------------------------------------------------------
# MIDI options
# -----------------------------------------------------------------------------
[midi]

# Set the baud rate used for GPIO MIDI.
#
# For connecting to standard MIDI devices (i.e. via DIN cable), this should be
# left at the default rate of 31250.
#
# For connecting to PCs, set this to match the baud rate of the other host.
# SoftMPU's serial MIDI mode, for example, uses a baud rate of 38400.
#
# Values: 300-4000000 (31250*)
gpio_baud_rate = 31250

# Enable or disable software "MIDI thru" on the GPIO Tx pin.
#
# When enabled, all data received via the GPIO Rx pin will be re-transmitted
# verbatim on the Tx pin. This may be useful for debugging or for passing MIDI
# data through to another synth.
#
# Values: on, off*
gpio_thru = off

# -----------------------------------------------------------------------------
# Audio options
# -----------------------------------------------------------------------------
[audio]

# Select audio output device.
#
# Values: pwm*, i2s
#
# pwm: Use the headphone jack
# i2s: Use an I2S DAC
output_device = i2s

# Sample rate of audio output (Hz).
#
# mt32emu uses an internal sample rate of 32000Hz (just like the real hardware)
# which is then resampled to this value.
#
# FluidSynth renders at this sample rate directly.
#
# Values: 32000-192000 (48000*)
sample_rate = 48000

# Set audio rendering chunk size (samples).
#
# A single stereo frame of audio has two samples, and so this value is double
# the number of frames per chunk.
# The smaller the chunk size, the lower the latency, but too low a value will
# cause underruns (distortion artifacts).
#
# Latency is a function of chunk size and sample rate, for example:
# 256 samples / 2 channels / 48000Hz * 1000ms = 2.67ms of latency.
# See documentation for recommended values for various Raspberry Pi models.
#
# The minimum value varies depending on audio output device.
# For PWM, the minimum is 2, for I2S the minimum is 32.
#
# Values: 2-2048 (256*)
chunk_size = 256

# Set address (hexadecimal) of I2C DAC control interface.
#
# This will be used for the initialization sequence (see below) if enabled.
# You can find the address of your DAC by using the i2cdetect utility in Linux.
#
# Values: 00-80 (4c*)
i2c_dac_address = 4c

# Select an initialization sequence for the DAC.
#
# Some DACs require some initialization commands to be sent via I2C before they
# will produce any sound.
#
# Values: none*, pcm51xx
#
# pcm51xx: for DACs based on PCM5121 or similar (e.g. PCM5141, PCM5242)
i2c_dac_init = pcm51xx
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

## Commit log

2021-05-07 Initial commit: Rear/Front PCB v1.0
    [minisynth32.kicad_pcb, minisynth32.sch]
2021-05-08 Move ROT_HDR for RPi 3B
    [minisynth32.kicad_pcb]
2021-05-10 Add separate PCB files, gerbers, readme, license, bom
    [minisynth32-B_Cu.gbl, minisynth32-B_Mask.gbs, minisynth32-B_SilkS.gbo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]
2021-05-11 Add 3D models
    [backplate.FCStd, backplate.stl, base.FCStd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]
2021-05-11 Update shell, README
    face:
    - add clearance to edges and bolt mounts
    - add hex nut pockets to bolt mounts
    - add face lines to imitate MT-32 display plate
    face, base, top:
    - new mating lips with more clearance
    base, top:
    - new mating lips similar to face
    - Minor updates to README
    - Delete old backplate model
    Also add .FCStd1 (FreeCAD backup files) to .gitignore
    [backplate.FCStd, backplate.stl, base.FCStd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]
2021-05-13 PCB rev 1.1 (rear only): cutaway to support RPi3B
    [minisynth32-B_Cu.gbl, minisynth32-B_Mask.gbs, minisynth32-B_SilkS.gbo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]
2021-05-15 Rev 1.1 F/R PCBs, tuned base and top
    [base.FCStd, base.stl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]
2021-05-17 Minor 3D updates and documentation
    [base.FCStd, base.stl, knob-3.0mm.FCStd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]
2021-05-18 Minor updates to face
    - standardise cuts for the threaded inserts
    - add hard support for knobwall
    [face.FCStd, face.stl]
2021-05-30 Change Pi mounting to M2.5 bolts
    Updated BOM/README/CHANGELOG to suit.
    Also properly rotated face "knobwall" hard support so it doesn't interfere with the backplate.
    [base.FCStd, base.stl, face.FCStd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]
2021-07-08 Documentation updates
    [minisynth32-bom.csv]
2021-08-01 WIP face v2
    [face.FCStd]
2021-08-01 Add rebackplate.FCstd (only had STL there)
    [rebackplate.FCStd]
2021-08-17 face v2
    [base.FCStd, base.stl, button.FCStd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]
2021-08-25 front pcb v2
    [face.FCStd, face.stl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]
2021-08-26 doco and stuff
    [minisynth32-bom.csv, shim-1.2mm.stl, shim-2mm.stl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]
2021-09-01 10-button updates
    [buttonmatrix.FCStd, buttonmatrix.stl, buttonmatrix2.FCStd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]
2021-09-06 arduino pro micro variant of base
    [base-apm.stl, base-din.stl, base.FCStd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]
2021-09-07 add MIDIUARTUSB, clean up models, update BOM
    [buttonmatrix.FCStd, buttonmatrix.stl, buttonsheet-2button.stl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]
2021-09-28 remove oled clearance as it was causing artifacts in the front face
    [face.FCStd, face.stl]
2021-10-02 updates to 3d models
    - redo bottom lip to suit base tabs
    - rework clearance cuts
    base:
    - tune reclearancefill
    - work on usb apm mount
    apmclamp:
    - bolt-from-bottom clamp to secure arduino pro micro from top
    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
    [apmclamp.FCStd, apmclamp.stl, base-apm.stl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]
2021-10-06 Update models
    - fix base wall mirroring (was incorrectly rotated before)
    - rework MCU base to fit different types of MCU board
    - add parametric (via spreadsheet) MCU clamp
    - remove 2mm shim STL as testing showed it too thick for thin OLED board
    [apmclamp.FCStd, apmclamp.stl, base-apm.stl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]
2021-10-06 render face-2but and create separate tree in FCStd
    [face-2but.stl, face.FCStd]
2021-10-07 Silkscreen update to front and F/R PCBs
    Updated Silkscreen text for extra buttons to read "NOT FUNCTIONAL" instead of "UNUSED", and got rid of the cross through them to avoid confusion.
    [minisynth32-B_Cu.gbl, minisynth32-B_Mask.gbs, minisynth32-B_SilkS.gbo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]
2021-10-07 Update BOM and README
    Also re-add 2mm shim
    [minisynth32-bom.csv, shim-2mm.stl, shim.FCStd]
2021-10-07 Lower MCU default boardheight to 5mm
    [mcuclamp-arduino-micro.stl, mcuclamp-sparkfun-pro-micro.stl, mcuclamp.FCStd]
2021-10-08 lengthen lip on top shell
    [top.FCStd, top.stl]
2021-10-09 minor fixes to BOM
    [minisynth32-bom.csv]

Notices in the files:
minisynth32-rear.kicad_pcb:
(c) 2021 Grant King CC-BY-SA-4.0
